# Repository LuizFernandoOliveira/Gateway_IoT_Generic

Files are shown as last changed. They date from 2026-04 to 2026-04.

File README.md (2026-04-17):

# Gateway IoT Multi-Protocolo (MSP430 version)





## Descrição
Diferentemente das tradicionais SBCs baseadas em MPUs de alta performance, este circuito de Gateway IoT é baseado em um MCU para aplicações que necessitam gerenciar a sua rede IoT no modo ultra-low power.

<p align="center">
  Gateway IoT MSP430
</p>

---

## Descrições técnicas
- Microcontrolador: MSP430FR6005;
- Alimentação externa de 5V;
- Possui a capacidade de realizar a comunicação com até 4 periféricos UARTs padrão FAPLO;
- Capacidade de se comunicar por meio do protocolo de comunicação:
  - 4 x UARTs (UART0, UART1, UART2, UART3);
  - 1 x RS-485 (UART2);
  - 1 x I2C (UART1);
  - 2 x SPIs (UART0 e UART1);
- Possui LEDs de troca de dados da UART0;
- Todos os demais pinos dos conectores padrão FAPLO podem ser usados como pinos de propósito gerais.

---

## Estrutura do repositório
Os arquivos de hardware foram desenvolvidos utilizando o KiCad 9.0.
- **`.kicad_pcb`**: Layout da placa de circuito impresso (Board).
- **`.kicad_sch`**: Esquemático eletrônico do sistema (Schematic).
- **`.kicad_pro`**: Gerenciador de projeto do KiCad (Project).

---

## Autor
**Dr. Luiz Fernando Pinto de Oliveira**

*Engenheiro Eletrônico especializado em Sistemas Embarcados e Ultra-Low Power.*
- **Website:** [FAPLO](https://faplo.webnode.page/)
- **LinkedIn:** [lfpo](https://www.linkedin.com/in/lfpo/)

---

Shield: [][cc-by-nc-nd]

This work is licensed under a
[Creative Commons Attribution-NonCommercial-NoDerivs 4.0 International License][cc-by-nc-nd].

[][cc-by-nc-nd]

[cc-by-nc-nd]: http://creativecommons.org/licenses/by-nc-nd/4.0/
[cc-by-nc-nd-image]: https://licensebuttons.net/l/by-nc-nd/4.0/88x31.png
[cc-by-nc-nd-shield]: https://img.shields.io/badge/License-CC%20BY--NC--ND%204.0-lightgrey.svg

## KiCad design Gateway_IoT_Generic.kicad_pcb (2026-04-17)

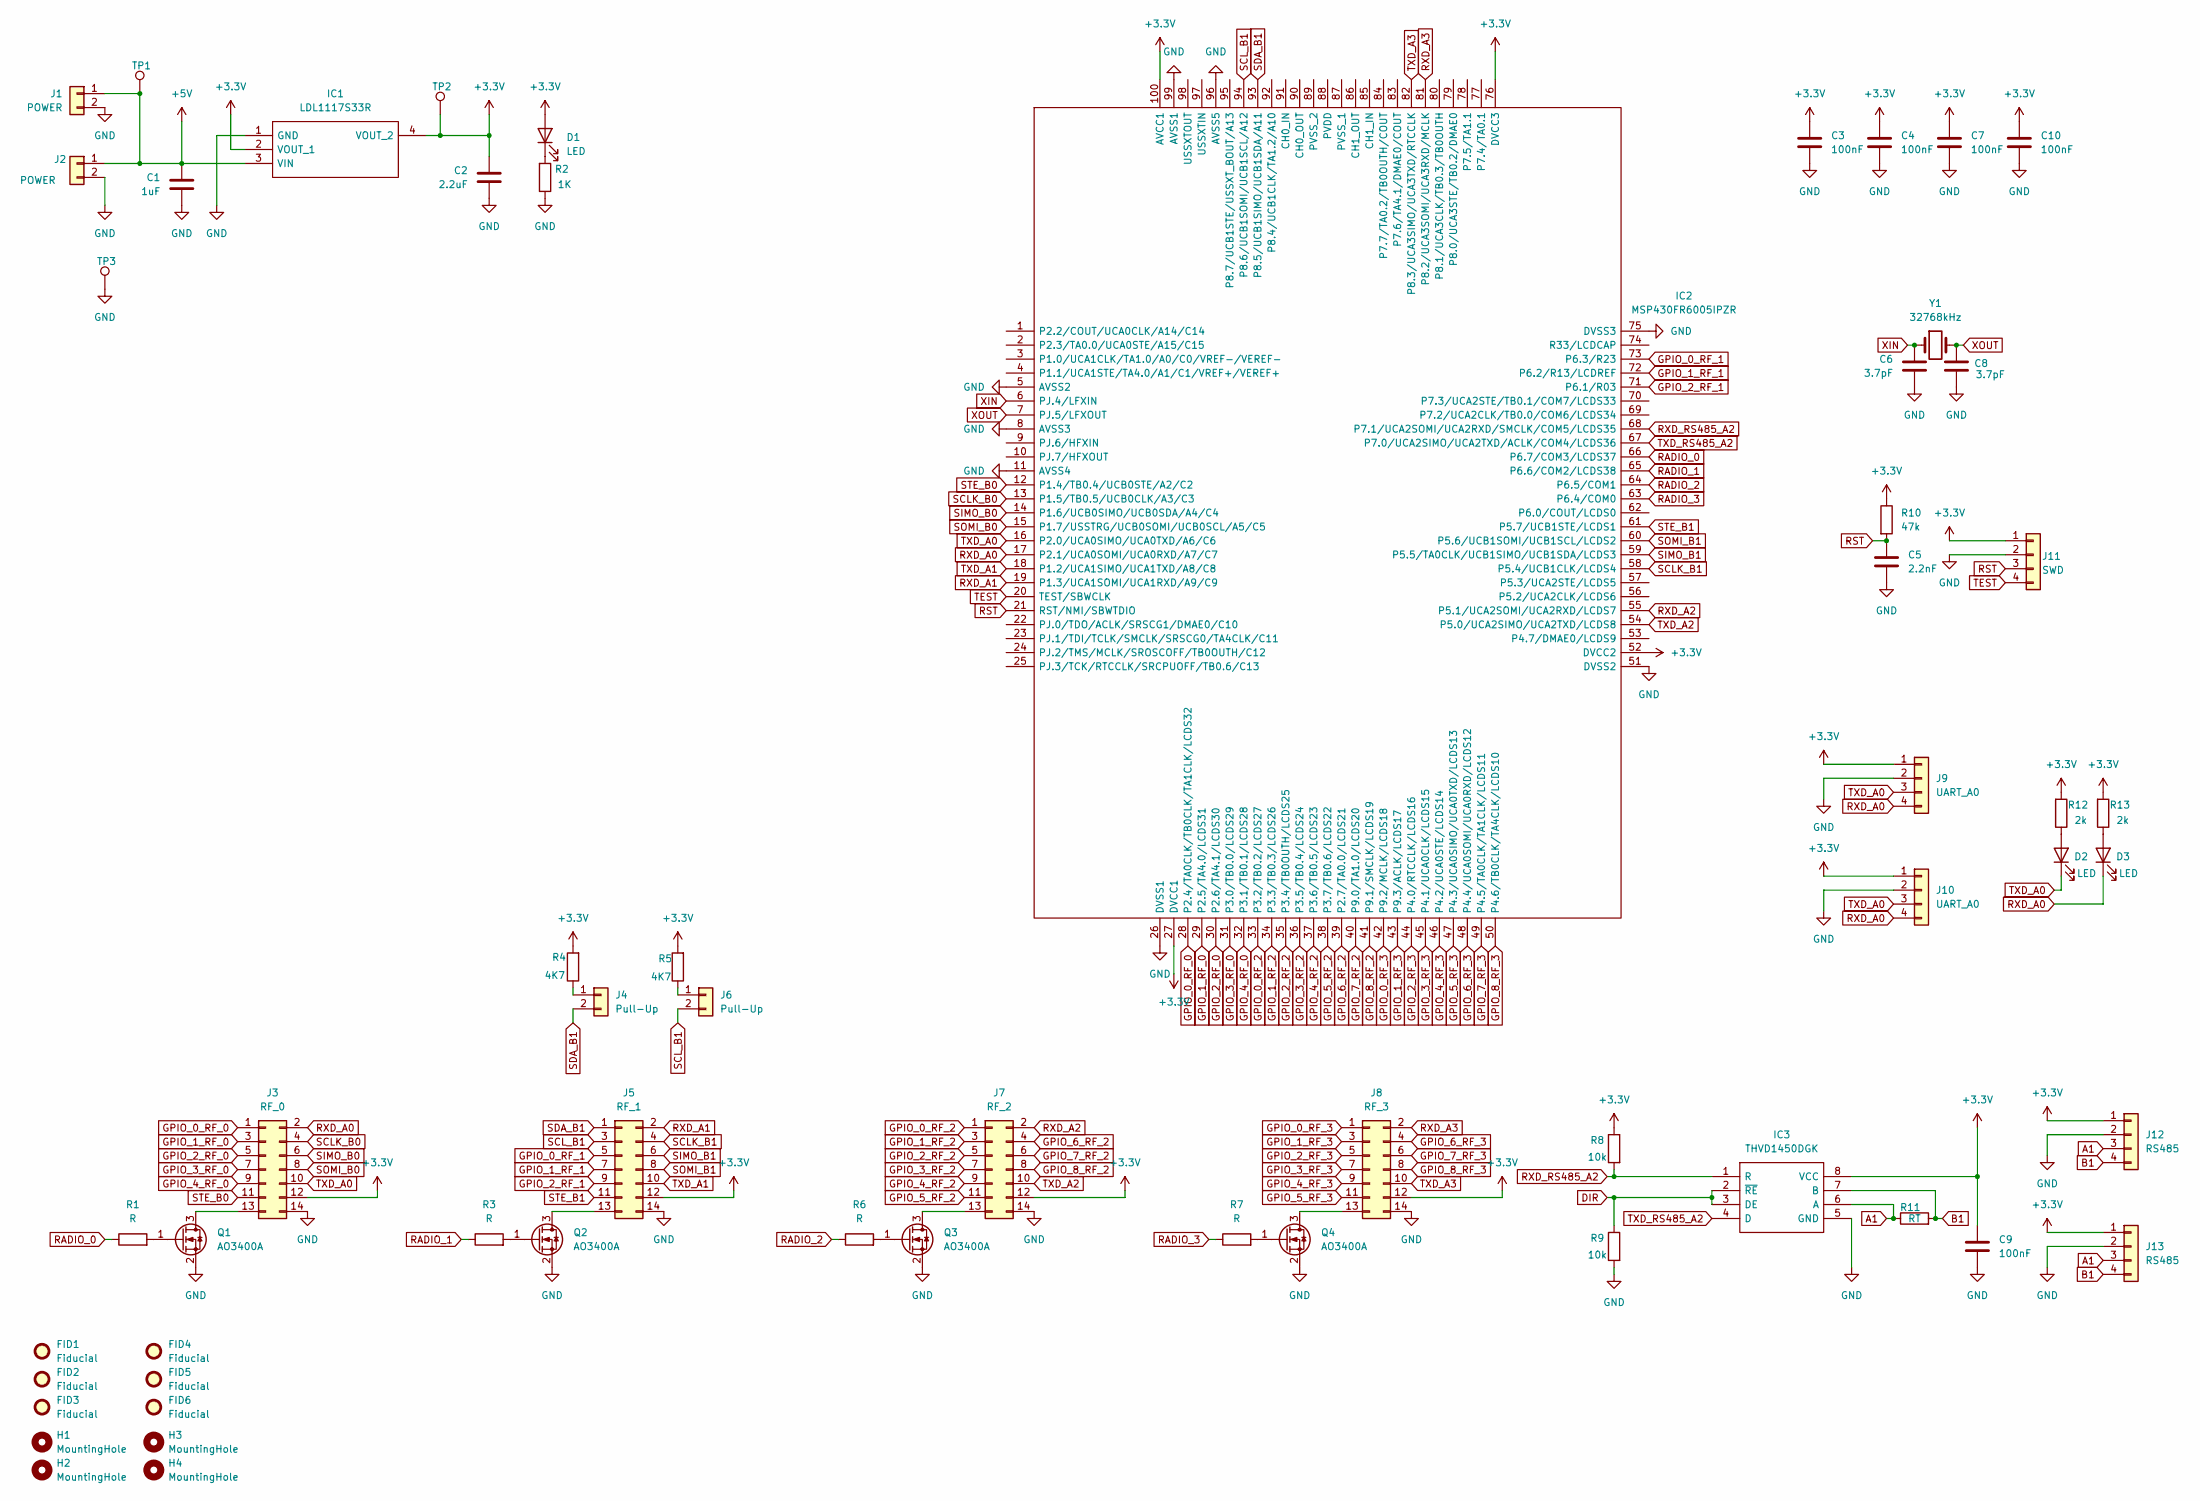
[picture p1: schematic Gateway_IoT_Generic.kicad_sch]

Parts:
C1: 1uF; C_0805_2012Metric
C2: 2.2uF; C_0805_2012Metric
C3, C4, C7, C9, C10: 100nF; C_0805_2012Metric
C5: 2.2nF; C_0805_2012Metric
C6, C8: 3.7pF; C_0805_2012Metric
D1, D2, D3: LED; LED_0805_2012Metric
FID1, FID2, FID3, FID4, FID5, FID6: Fiducial; Fiducial_1mm_Mask2mm
H1, H2, H3, H4: MountingHole; MountingHole_3.2mm_M3_DIN965
IC1: LDL1117S33R; SOT230P700X180-4N; Manufacturer_Part_Number LDL1117S33R; Mouser Part Number 511-LDL1117S33R
IC2: MSP430FR6005IPZR; QFP50P1600X1600X160-100N; Manufacturer_Part_Number MSP430FR6005IPZR; Mouser Part Number 595-MSP430FR6005IPZR
IC3: THVD1450DGK; SOP65P490X110-8N; Manufacturer_Part_Number THVD1450DGK; Mouser Part Number 595-THVD1450DGK
J1: POWER; PinHeader_1x02_P2.54mm_Vertical
J2: POWER; BarrelJack_Horizontal
J3: RF_0; PinHeader_2x07_P2.54mm_Vertical
J4, J6: Pull-Up; PinHeader_1x02_P2.54mm_Vertical
J5: RF_1; PinHeader_2x07_P2.54mm_Vertical
J7: RF_2; PinHeader_2x07_P2.54mm_Vertical
J8: RF_3; PinHeader_2x07_P2.54mm_Vertical
J9: UART_A0; PinHeader_1x04_P2.54mm_Vertical
J10: UART_A0; JST_XH_S4B-XH-A_1x04_P2.50mm_Horizontal
J11: SWD; PinHeader_1x04_P1.27mm_Vertical
J12: RS485; PinHeader_1x04_P2.54mm_Vertical
J13: RS485; PhoenixContact_MSTBA_2,5_4-G-5,08_1x04_P5.08mm_Horizontal
Q1, Q2, Q3, Q4: AO3400A; SOT-23
R1, R3, R6, R7: R; R_0805_2012Metric
R2: 1K; R_0805_2012Metric
R4, R5: 4K7; R_0805_2012Metric
R8, R9: 10k; R_0805_2012Metric
R10: 47k; R_0805_2012Metric
R11: RT; R_1206_3216Metric
R12, R13: 2k; R_0805_2012Metric
TP1, TP2, TP3: TestPoint; TestPoint_Loop_D1.80mm_Drill1.0mm_Beaded
Y1: 32768kHz; D_0805_2012Metric

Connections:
+3.3V: C2.1, C3.1, C4.1, C7.1, C9.1, C10.1, D1.2 (A), IC1.2 (VOUT_1), IC1.4 (VOUT_2), IC2.27 (DVCC1), IC2.52 (DVCC2), IC2.76 (DVCC3), IC2.100 (AVCC1), IC3.8 (VCC), J3.12, J5.12, J7.12, J8.12, J9.1, J10.1, J11.1, J12.1, J13.1, R4.2, R5.2, R8.1, R10.1, R12.2, R13.2, TP2.1
+5V: C1.1, IC1.3 (VIN), J1.1, J2.1, TP1.1
A1: IC3.6 (A), J12.3, J13.3, R11.1
B1: IC3.7 (B), J12.4, J13.4, R11.2
DIR: IC3.2 (~RE), IC3.3 (DE), R9.1
GND: C1.2, C2.2, C3.2, C4.2, C5.2, C6.2, C7.2, C8.2, C9.2, C10.2, IC1.1 (GND), IC2.5 (AVSS2), IC2.8 (AVSS3), IC2.11 (AVSS4), IC2.26 (DVSS1), IC2.51 (DVSS2), IC2.75 (DVSS3), IC2.96 (AVSS5), IC2.99 (AVSS1), IC3.5 (GND), J1.2, J2.2, J3.14, J5.14, J7.14, J8.14, J9.2, J10.2, J11.2, J12.2, J13.2, Q1.2 (S), Q2.2 (S), Q3.2 (S), Q4.2 (S), R2.1, R9.2, TP3.1
GPIO_0_RF_0: IC2.28 (P2.4/TA0CLK/TB0CLK/TA1CLK/LCDS32), J3.1
GPIO_0_RF_1: IC2.73 (P6.3/R23), J5.5
GPIO_0_RF_2: IC2.33 (P3.2/TB0.2/LCDS27), J7.1
GPIO_0_RF_3: IC2.42 (P9.2/MCLK/LCDS18), J8.1
GPIO_1_RF_0: IC2.29 (P2.5/TA4.0/LCDS31), J3.3
GPIO_1_RF_1: IC2.72 (P6.2/R13/LCDREF), J5.7
GPIO_1_RF_2: IC2.34 (P3.3/TB0.3/LCDS26), J7.3
GPIO_1_RF_3: IC2.43 (P9.3/ACLK/LCDS17), J8.3
GPIO_2_RF_0: IC2.30 (P2.6/TA4.1/LCDS30), J3.5
GPIO_2_RF_1: IC2.71 (P6.1/R03), J5.9
GPIO_2_RF_2: IC2.35 (P3.4/TB0OUTH/LCDS25), J7.5
GPIO_2_RF_3: IC2.44 (P4.0/RTCCLK/LCDS16), J8.5
GPIO_3_RF_0: IC2.31 (P3.0/TB0.0/LCDS29), J3.7
GPIO_3_RF_2: IC2.36 (P3.5/TB0.4/LCDS24), J7.7
GPIO_3_RF_3: IC2.45 (P4.1/UCA0CLK/LCDS15), J8.7
GPIO_4_RF_0: IC2.32 (P3.1/TB0.1/LCDS28), J3.9
GPIO_4_RF_2: IC2.37 (P3.6/TB0.5/LCDS23), J7.9
GPIO_4_RF_3: IC2.46 (P4.2/UCA0STE/LCDS14), J8.9
GPIO_5_RF_2: IC2.38 (P3.7/TB0.6/LCDS22), J7.11
GPIO_5_RF_3: IC2.47 (P4.3/UCA0SIMO/UCA0TXD/LCDS13), J8.11
GPIO_6_RF_2: IC2.39 (P2.7/TA0.0/LCDS21), J7.4
GPIO_6_RF_3: IC2.48 (P4.4/UCA0SOMI/UCA0RXD/LCDS12), J8.4
GPIO_7_RF_2: IC2.40 (P9.0/TA1.0/LCDS20), J7.6
GPIO_7_RF_3: IC2.49 (P4.5/TA0CLK/TA1CLK/LCDS11), J8.6
GPIO_8_RF_2: IC2.41 (P9.1/SMCLK/LCDS19), J7.8
GPIO_8_RF_3: IC2.50 (P4.6/TB0CLK/TA4CLK/LCDS10), J8.8
unnamed: D1.1 (K), R2.2
unnamed: D2.2 (A), R12.1
unnamed: D3.2 (A), R13.1
unnamed: J3.13, Q1.3 (D)
unnamed: J4.1, R4.1
unnamed: J5.13, Q2.3 (D)
unnamed: J6.1, R5.1
unnamed: J7.13, Q3.3 (D)
unnamed: J8.13, Q4.3 (D)
unnamed: Q1.1 (G), R1.2
unnamed: Q2.1 (G), R3.2
unnamed: Q3.1 (G), R6.2
unnamed: Q4.1 (G), R7.2
RADIO_0: IC2.66 (P6.7/COM3/LCDS37), R1.1
RADIO_1: IC2.65 (P6.6/COM2/LCDS38), R3.1
RADIO_2: IC2.64 (P6.5/COM1), R6.1
RADIO_3: IC2.63 (P6.4/COM0), R7.1
RST: C5.1, IC2.21 (RST/NMI/SBWTDIO), J11.3, R10.2
RXD_A0: D3.1 (K), IC2.17 (P2.1/UCA0SOMI/UCA0RXD/A7/C7), J3.2, J9.4, J10.4
RXD_A1: IC2.19 (P1.3/UCA1SOMI/UCA1RXD/A9/C9), J5.2
RXD_A2: IC2.55 (P5.1/UCA2SOMI/UCA2RXD/LCDS7), J7.2
RXD_A3: IC2.81 (P8.2/UCA3SOMI/UCA3RXD/MCLK), J8.2
RXD_RS485_A2: IC2.68 (P7.1/UCA2SOMI/UCA2RXD/SMCLK/COM5/LCDS35), IC3.1 (R), R8.2
SCLK_B0: IC2.13 (P1.5/TB0.5/UCB0CLK/A3/C3), J3.4
SCLK_B1: IC2.58 (P5.4/UCB1CLK/LCDS4), J5.4
SCL_B1: IC2.94 (P8.6/UCB1SOMI/UCB1SCL/A12), J5.3, J6.2
SDA_B1: IC2.93 (P8.5/UCB1SIMO/UCB1SDA/A11), J4.2, J5.1
SIMO_B0: IC2.14 (P1.6/UCB0SIMO/UCB0SDA/A4/C4), J3.6
SIMO_B1: IC2.59 (P5.5/TA0CLK/UCB1SIMO/UCB1SDA/LCDS3), J5.6
SOMI_B0: IC2.15 (P1.7/USSTRG/UCB0SOMI/UCB0SCL/A5/C5), J3.8
SOMI_B1: IC2.60 (P5.6/UCB1SOMI/UCB1SCL/LCDS2), J5.8
STE_B0: IC2.12 (P1.4/TB0.4/UCB0STE/A2/C2), J3.11
STE_B1: IC2.61 (P5.7/UCB1STE/LCDS1), J5.11
TEST: IC2.20 (TEST/SBWCLK), J11.4
TXD_A0: D2.1 (K), IC2.16 (P2.0/UCA0SIMO/UCA0TXD/A6/C6), J3.10, J9.3, J10.3
TXD_A1: IC2.18 (P1.2/UCA1SIMO/UCA1TXD/A8/C8), J5.10
TXD_A2: IC2.54 (P5.0/UCA2SIMO/UCA2TXD/LCDS8), J7.10
TXD_A3: IC2.82 (P8.3/UCA3SIMO/UCA3TXD/RTCCLK), J8.10
TXD_RS485_A2: IC2.67 (P7.0/UCA2SIMO/UCA2TXD/ACLK/COM4/LCDS36), IC3.4 (D)
XIN: C6.1, IC2.6 (PJ.4/LFXIN), Y1.1
XOUT: C8.1, IC2.7 (PJ.5/LFXOUT), Y1.2

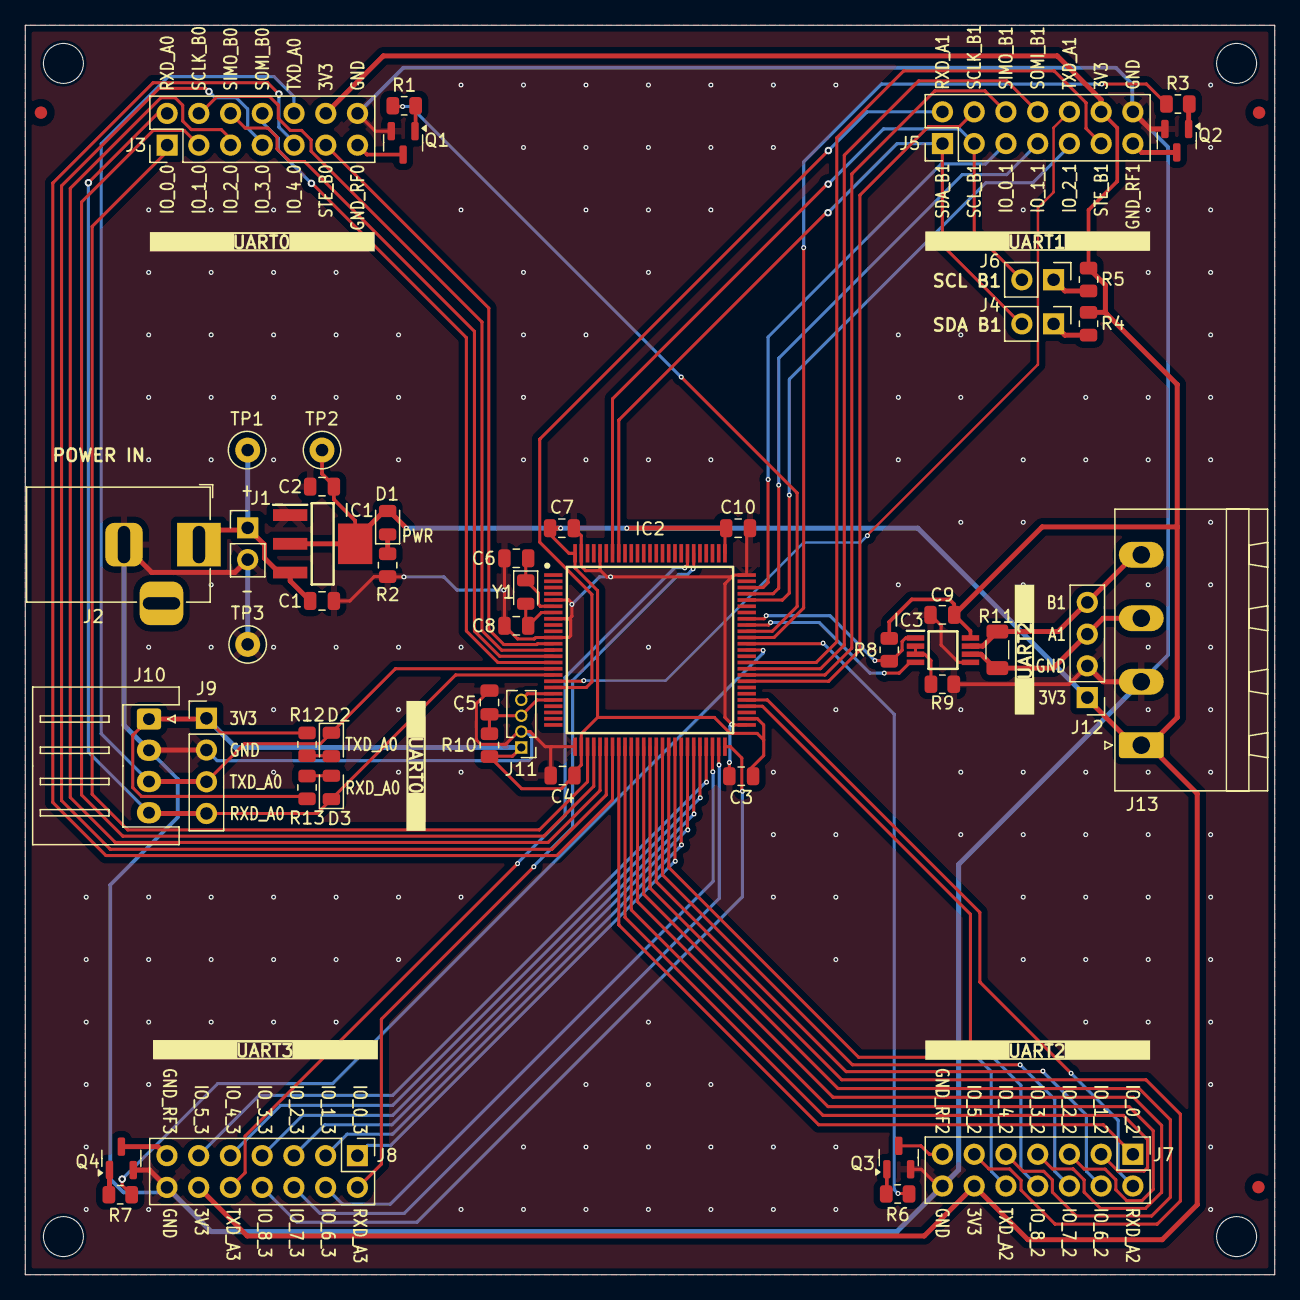
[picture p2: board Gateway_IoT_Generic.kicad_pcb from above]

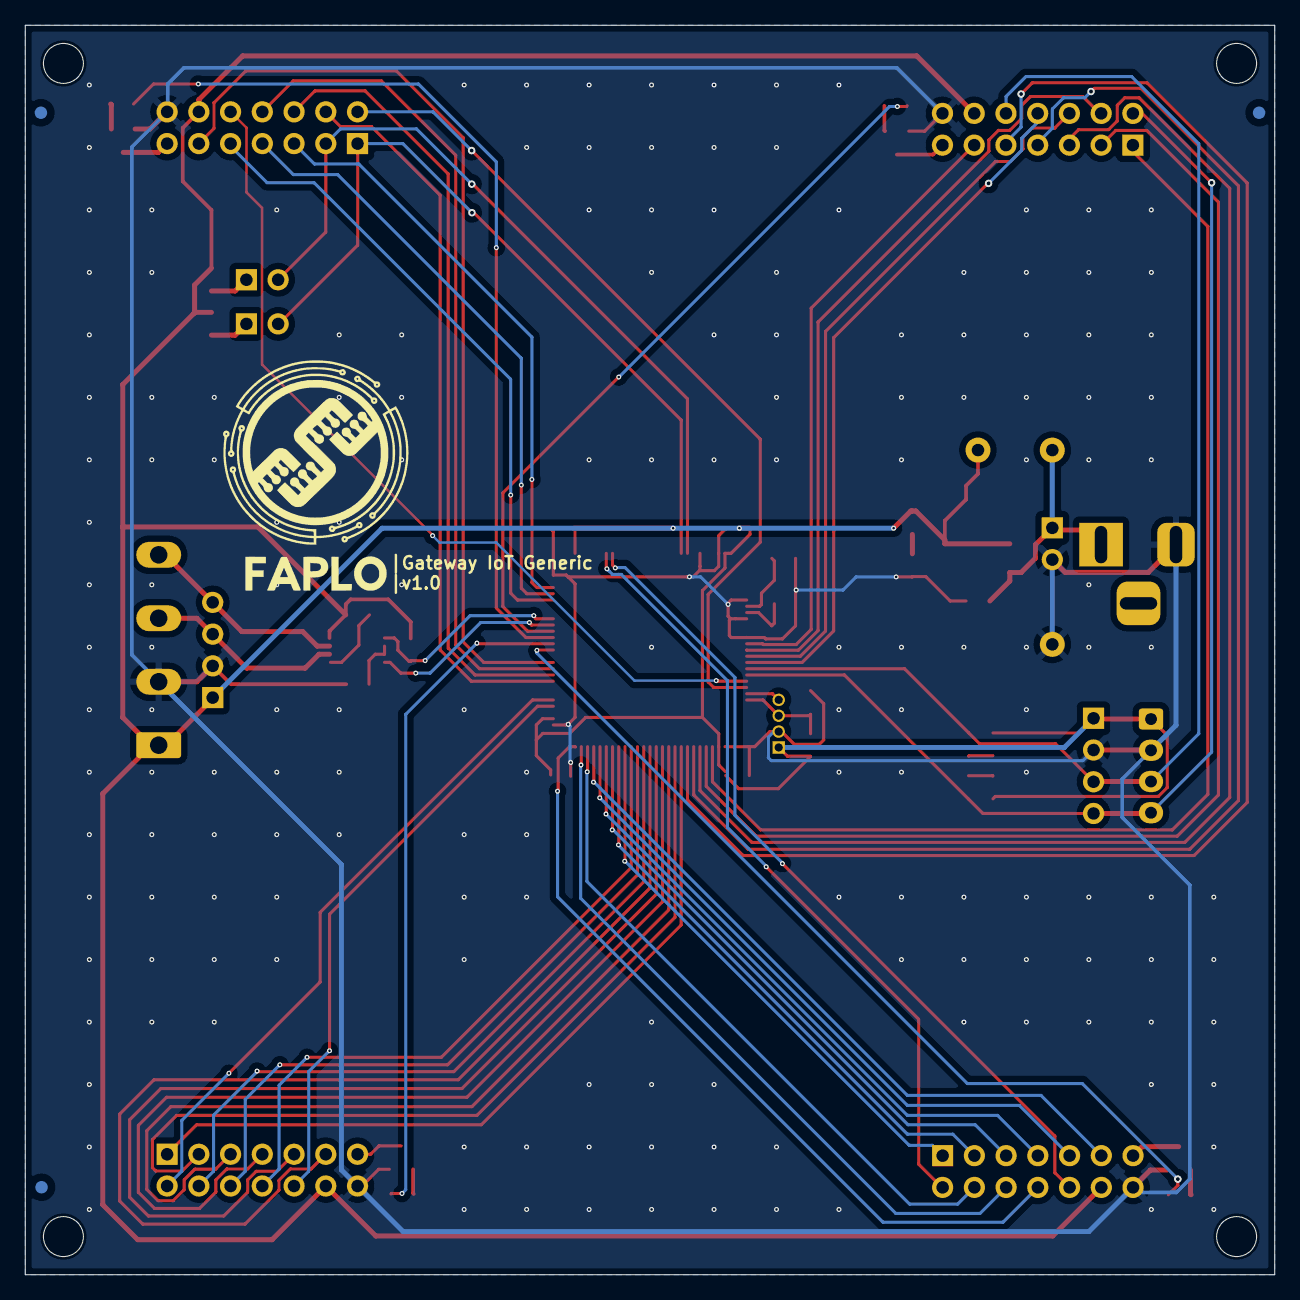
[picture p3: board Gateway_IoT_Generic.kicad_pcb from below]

Board: 2 copper layers, 100.0 x 100.0 mm, 60 parts (3 on the bottom side), 73 nets.

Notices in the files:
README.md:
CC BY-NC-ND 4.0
